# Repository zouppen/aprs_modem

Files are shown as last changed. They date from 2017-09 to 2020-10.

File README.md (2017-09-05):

# aprs_modem
APRS modem using ATmega32u4 and HX1 radio module

## License

This program is free software: you can redistribute it and/or modify
it under the terms of the GNU Affero General Public License as
published by the Free Software Foundation, either version 3 of the
License, or (at your option) any later version.

This program is distributed in the hope that it will be useful, but
WITHOUT ANY WARRANTY; without even the implied warranty of
MERCHANTABILITY or FITNESS FOR A PARTICULAR PURPOSE.  See the GNU
Affero General Public License for more details.

You should have received a copy of the GNU Affero General Public
License along with this program.  If not, see
<http://www.gnu.org/licenses/>.

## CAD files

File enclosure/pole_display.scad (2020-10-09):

use <powerpolish.scad>

// Test print for "standard" pair of plugs
translate([0,0,cupdepth+16.6]) rotate([0,90,0]) poles(2);

// Test print for casing
translate([11,0,cupdepth+wedge_slope*lower_pole_inner_h+thinwall]) rotate([0,90,0]) {
    poles(2,wedge_slope*lower_pole_inner_h+thinwall, framing=true, tongue=false);
}

// Test print for powerpole cap
translate([21,0,cupdepth+cupwidth/2]) rotate([0,90,0]) {
    poles(2,cupwidth/2, tongue=false, cap=true);
}

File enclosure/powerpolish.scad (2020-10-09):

// Anderson PowerPole like housing
// compatible with original contacts.

thinwall=0.8;
cupdepth=8.25;
cupwidth=7.6;
margin=0.2; // make the lower part a bit smaller
backwall=2*thinwall+margin/2;
tongue_angle=18;
tongue_thickness=1;
tongue_rise=7; // Adjust this with the angle
tongue_depth=2.6; // From connector tip to tongue tip
tongue_width=3.5; // On y axis
tonguelike_h = 1.3; // Tongue replacement height
conn_spacing=7.9; // Spacing between connectors
hole_x = 10;
hole_r = 1.1;
wedge_slope = 0.4; // 3D printing aid wedges

// Some magic values
lower_pole_inner_h = cupwidth/2-backwall;

// Square pipe, from origo
module sqpipe(d, w, h, wall) {
    difference() {
        cube([d,w,h]);
        translate([-wall,wall,wall]) {
            cube([d+2*wall,w-2*wall,h-2*wall]);
        }
    }
}

// PowerPolish contact cup, centered on y axis and nudged on z axis
module poletip(d, w, h, wall, wall_bottom, fill=false) {
    difference() {
        // Outer
        translate([0,-w/2,0]) cube([d,w,h]);
        // Inner
        if (!fill)
            translate([-thinwall,-w/2+wall,-wall_bottom]) cube([d,w-2*wall,h]);
    }
}

module pole(backdepth, tongue, cap) {
    // Front part
    difference() {
        union() {
            // Upper part
            poletip(cupdepth+thinwall, cupwidth, cupwidth/2, thinwall, thinwall);
            // Lower part
            rotate([180,0,180]) {
                translate([-(cupdepth+thinwall),0,0]) {
                    lower_pole_h = cupwidth/2-thinwall-margin;
                    poletip(cupdepth+thinwall, cupwidth-2*thinwall-margin, lower_pole_h, thinwall, lower_pole_h - lower_pole_inner_h, cap);
                }
            }
        }
        cube([2*cupdepth,cupwidth+margin,margin], center=true);
    }

    if (cap) {
        // Draw nothing
    } else if (tongue) {
        // Emulates a metal strip
        translate([tongue_rise+tongue_depth,0,-cupwidth/2+thinwall+margin]) {
            tongue(tongue_angle, tongue_width, tongue_rise, tongue_thickness);
        }
    } else {
        // For PCB mounts
        tonguelike_x = cupdepth*0.3; // Visual guess
        translate([tongue_depth,-cupwidth/2+thinwall+margin/2,-lower_pole_inner_h]) {
            cube([tonguelike_x,cupwidth-2*thinwall-margin,tonguelike_h]);
        }
        // PCB mount platform wedge
        translate([tongue_depth+tonguelike_x,cupwidth/2-thinwall-margin/2,-lower_pole_inner_h]) {
            rotate([90,0,0]) wedge(tonguelike_h,wedge_slope,cupwidth-2*thinwall-margin);
        }
    }

    // Cap back is rendered in poles function
    if (!cap) {
        // Back part
        translate([cupdepth,-cupwidth/2,-cupwidth/2]) {
            sqpipe(backdepth, cupwidth, cupwidth, backwall);
        }

        // Back weddge to ease printing
        translate([cupdepth+thinwall,-cupwidth/2,cupwidth/2-backwall]) rotate([90,180,180]) wedge(cupwidth/2-backwall,wedge_slope,cupwidth);
    }
    
    // Front wedge
    lower_height=cupwidth/2-thinwall-1.5*margin;
    translate([thinwall,cupwidth/2-thinwall-margin/2,-lower_height-margin/2]) rotate([90,0,0]) wedge(lower_height,wedge_slope,cupwidth-2*thinwall-margin);
    
}

module tongue(angle, width, length, thickness) {
    intersection () {
        difference() {
            rotate([0,angle,0]) {
                cube([3*length,width,thickness], center=true);
            }
            translate([0,0,-length]) {
                cube([3*length,width*2,2*length], center=true);
            }
        }
        cube([2*length, 2*width, length*2], center=true); 
    }
}

module poles(count, backdepth=16.6, framing=false, tongue=true, cap=false) {
    ends = framing ? [0 : 1: count] : [1 : 1: count-1];

    difference() {
        union() {
            // Actual poles
            for (i = [0 : 1: count-1]) {
                translate([0,conn_spacing*i,0]) {
                    pole(backdepth, tongue, cap);
                }
            }

            // Fill gaps between the poles
            for (i = ends) {
                translate([0,conn_spacing*i,0]) {
                    gapwidth=conn_spacing-cupwidth;
                    translate([0,(-conn_spacing-gapwidth)/2,margin/2]) {
                        cube([backdepth+cupdepth,gapwidth,cupwidth/2-margin/2]);
                    }
                    translate([cupdepth, cupwidth/2-conn_spacing, -cupwidth/2]) {
                        cube([backdepth, gapwidth, cupwidth]);
                    }
                }
            }

            if (cap) {
                translate([cupdepth, -cupwidth/2, -cupwidth/2]) {
                    cube([backdepth, (count-1)*conn_spacing+cupwidth, cupwidth]);
                }
            }
            
            // Add bottom support if framing used
            if (framing) {
                // Inner gap
                translate([cupdepth,cupwidth/2-conn_spacing,-cupwidth/2]) {
                    mirror([0,0,1]) {
                        cube([backdepth,(count+1)*conn_spacing-cupwidth,conn_spacing-cupwidth]);
                    }
                }
                // Lowest support
                translate([0,cupwidth/2-conn_spacing,-conn_spacing/2]) {
                    mirror([0,0,1]) {
                        cube([cupdepth+backdepth,(count+1)*conn_spacing-cupwidth,thinwall]);
                    }
                }
                
                // Side covers
                for (y_pos = [0, count*conn_spacing+thinwall]) {
                    translate([0,-thinwall-conn_spacing/2+y_pos,-conn_spacing/2-thinwall]) {
                        cube([cupdepth+backdepth,thinwall,cupwidth/2+conn_spacing/2+thinwall]);
                    }
                }
            }
        }
        
        // Add holes
        if (!framing && !cap) {
            for (i = [1 : 1 : count-1]) {
                translate([hole_x,i*conn_spacing-cupwidth/2,-cupwidth]) {
                    cylinder(cupwidth*2, hole_r, hole_r, $fn=16);
                }
            }
        }
    }
}

module wedge(x, slope, z) {
    linear_extrude(z)
        polygon([[0,0], [0,x], [slope*x,0]]);
}

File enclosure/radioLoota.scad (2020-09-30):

//pls don't judge too much
//my first .scad file

hyla=6;
hala=7;
h=hyla + hala + 2;
w=28;
l=60;
wall=3;

sisa =  [w,l,h];
ulko = [for (i = sisa) i+6];
usb = [9,4,wall];

module cube1(){
    difference() {
        translate ([0,0,-wall])cube(ulko);
        translate([wall,wall,0]) cube(sisa);
        }
}

module cube2(){
difference(){
    cube1();
    translate([8+wall,0,0]) cube(usb);
    }

}
module cube3(){
difference(){
    cube2();
    translate([0,(l+wall),0]) 
cube([100,100,h]);
    }
}

module cube4(){
difference(){
    cube3();
    rotate([0,90,0])
    translate([0,(l+wall),wall]) 
    cylinder(r=1,h=w);
    }
}

module cube5(){
difference(){
    cube4();
    rotate([0,90,0])
    translate([-h,(l+wall),wall]) 
    cylinder(r=1,h=w);
    }
}

cube5();
translate([2,0,hala - wall]) cube([wall,l,wall]);
translate([2,0,h-hyla]) cube([wall,l,wall]);

translate([w+1,0,hala - wall]) cube([wall,l,wall]);
translate([w+1,0,h-hyla]) cube([wall,l,wall]);

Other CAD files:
enclosure/radioLootaLid.scad

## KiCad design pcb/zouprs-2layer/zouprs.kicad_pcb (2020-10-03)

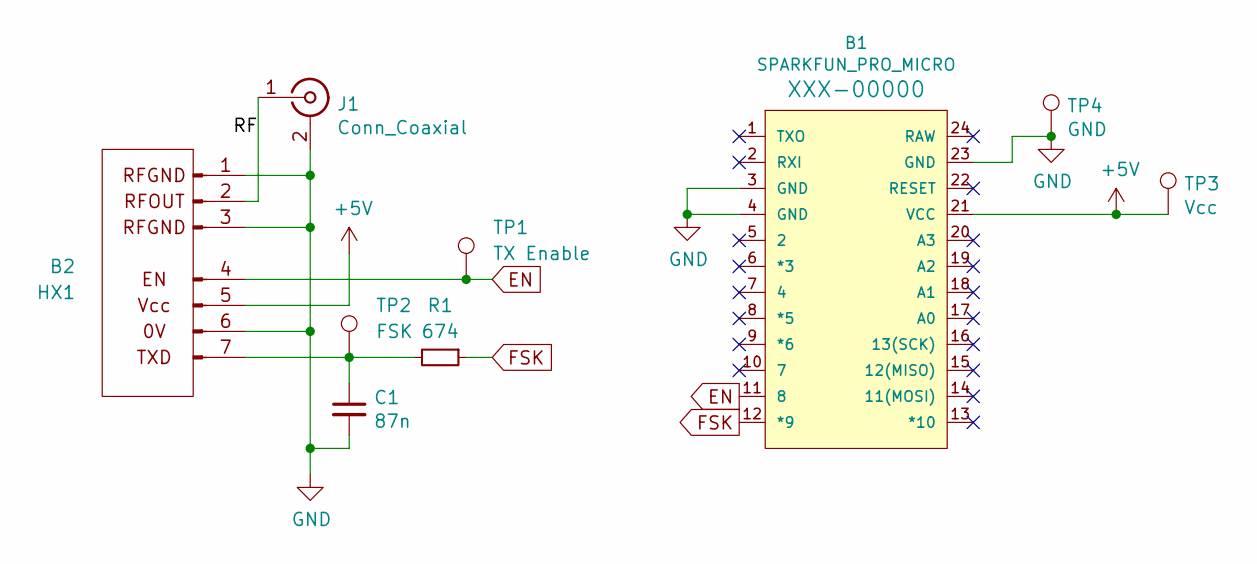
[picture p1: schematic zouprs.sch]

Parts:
B1: SPARKFUN_PRO_MICRO
B2: HX1; PinHeader_1x12_P2.54mm_Vertical
C1: 87n; C_1206_3216Metric_Pad1.42x1.75mm_HandSolder
J1: Conn_Coaxial; SMA_Samtec_SMA-J-P-X-ST-EM1_EdgeMount
R1: 674; R_1206_3216Metric_Pad1.42x1.75mm_HandSolder
TP1: TX Enable; TestPoint_Pad_D1.0mm
TP2: FSK; TestPoint_Pad_D1.0mm
TP3: Vcc; TestPoint_Pad_D1.0mm
TP4: GND; TestPoint_Pad_D1.0mm

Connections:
+5V: B1.21 (VCC), B2.5 (GND), TP3.1
EN: B1.11 (8), B2.4 (EN), TP1.1
FSK: B1.12 (*9), R1.1
GND: B1.3 (GND), B1.4 (GND), B1.23 (GND), B2.1 (RFGND), B2.3 (RFGND), B2.6 (VCC), C1.2, J1.2 (Ext), TP4.1
unnamed: B2.2 (RFOUT), J1.1 (In)
unnamed: B2.7 (TXD), C1.1, R1.2, TP2.1

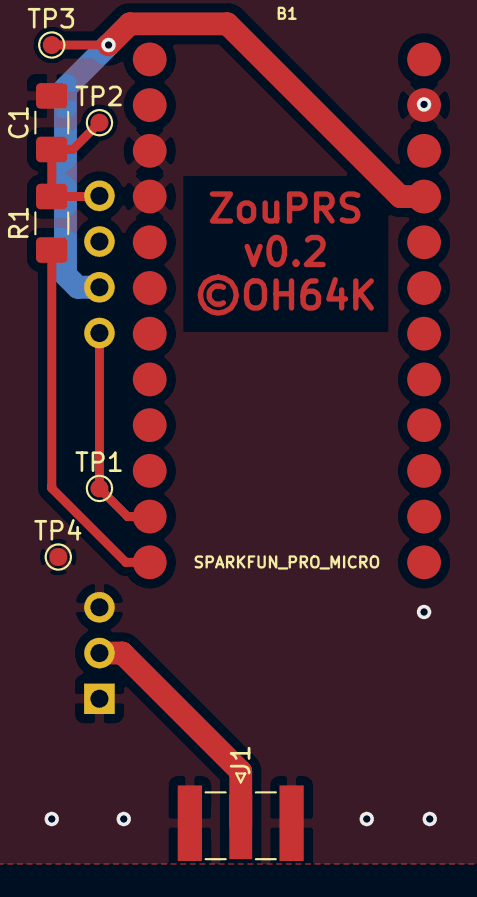
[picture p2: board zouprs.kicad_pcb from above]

Board: 2 copper layers, 9 parts (1 on the bottom side), 6 nets.

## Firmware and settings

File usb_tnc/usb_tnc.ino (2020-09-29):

// Include LibAPRS
#include <LibAPRS.h>
#include <TimerOne.h>

#define KISS_STATE_DATA 0
#define KISS_STATE_CMD 1
#define KISS_STATE_ESC 2
#define KISS_STATE_END 3

#define FEND 0xC0
#define FESC 0xDB
#define TFEND 0xDC
#define TFESC 0xDD

#define TXD_PIN 9
#define EN_PIN 8

extern Afsk *AFSK_modem;
extern AX25Ctx AX25;
uint8_t AFSK_dac_isr(Afsk *afsk);

void setup() {
    // Set up serial port
    Serial.begin(9600);
    pinMode(TXD_PIN, OUTPUT);
    
    Timer1.initialize(64); // set a timer of length 100000 microseconds (or 0.1 sec - or 10Hz => the led will blink 5 times, 5 cycles of on-and-off, per second)
    Timer1.pwm(TXD_PIN, 512);
    Timer1.attachInterrupt( timerIsr ); // attach the service routine here

    // Initialise APRS library - This starts the modem
    APRS_init(EN_PIN);
    DDRB &= ~(1<<0); // Start with RX LED off (or set to INPUT mode)
  
    // You must at a minimum configure your callsign and SSID
    APRS_setCallsign("OH6EYA", 1);
    APRS_setPreamble(250);
}

void loop() {
    static uint8_t msg[256];
    static uint8_t msg_i = 0;
    static uint8_t state = KISS_STATE_END;
  
    while (Serial.available()) {
	DDRB |= (1<<0); // Any serial traffic turns on RX LED
	uint8_t c = Serial.read();

	// Send if FEND and we have something to send
	if (c == FEND) {
	    if (state == KISS_STATE_DATA && msg_i != 0) {
		DDRB &= ~(1<<0); // Datagram completed, turn off RX LED
		ax25_sendRaw(&AX25, msg, msg_i);
		msg_i = 0;
	    }
	    state = KISS_STATE_CMD;
	    continue;
	}

	if (state == KISS_STATE_CMD) {
	    // We currently support only frame at first TNC
	    state = c == 0x00 ? KISS_STATE_DATA : KISS_STATE_END;
	    continue;
	}

	// Must set before decoding escapes
	if (state == KISS_STATE_DATA && c == FESC) {
	    state = KISS_STATE_ESC;
	    continue;
	}
	
	// Decode escape
	if (state == KISS_STATE_ESC) {
	    switch (c) {
	    case TFEND:
		c = FEND;
		break;
	    case TFESC:
		c = FESC;
		break;
	    default:
		// Garbage
		state = KISS_STATE_END;
		continue;
	    }
	    state = KISS_STATE_DATA;
	}

	if (state == KISS_STATE_DATA) {
	    if (msg_i >= sizeof(msg)) {
		// Too long content
		state = KISS_STATE_END;
	    } else {
		msg[msg_i++] = c;
	    }
	}
	// Else: error state; do nothing	
    }
}

void timerIsr()
{
    // Set new value for PWM
    Timer1.pwm(TXD_PIN, (int)AFSK_dac_isr(AFSK_modem) << 2);
}

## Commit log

2020-09-29 Make it support new ZouPRS board
2020-09-30 Enclosure added
    [radioLoota.scad, radioLootaLid.scad]
2020-09-30 minor tweaks
    [radioLoota.scad, radioLootaLid.scad]
2020-10-01 Add PCB
    [zouprs.kicad_pcb, zouprs.sch]
2020-10-03 Make dual side PCB
    [zouprs.kicad_pcb, zouprs.sch]
2020-10-03 Move Arduino board about 1mm up
    [zouprs.kicad_pcb]
2020-10-03 Add some ground vias to RF end of the board
    [zouprs.kicad_pcb]
2020-10-03 Small tweaks to test point
    [zouprs.kicad_pcb]
2020-10-06 Add simple "powerpolish" plug
    [powerpolish.scad]
2020-10-06 Outer dimensions match
    [powerpolish.scad]
2020-10-06 Add double powerpolish
    [powerpolish.scad]
2020-10-06 Add tongue
    [powerpolish.scad]
2020-10-06 Add some comments to the variables
    [powerpolish.scad]
2020-10-07 Add support for parametric pole arrays
    [powerpolish.scad]
2020-10-07 Add wedges for easier printing
    [powerpolish.scad]
2020-10-07 Tongue at too back, blocking the connector. Fixing.
    [powerpolish.scad]
2020-10-07 Add support for framing
    [powerpolish.scad]
2020-10-07 Add framing support for poles (case mount)
    [powerpolish.scad]
2020-10-08 Fix back wedge so that it's not inside back wall
    [powerpolish.scad]
2020-10-08 Fine-tune lower cup lower wall thickness. Calculate it form back wall thickness
    [powerpolish.scad]
2020-10-08 Make different kind of tongue to PCB mount block
    [powerpolish.scad]
2020-10-08 Fix slope math in wedges
    [powerpolish.scad]
2020-10-08 Add support for protective cap for Anderson Powerpole
    [powerpolish.scad]
2020-10-09 enclosure: Make cup of the cap filled to top
    [powerpolish.scad]
2020-10-09 enclosure: Tongue must be thicker to not to break
    [powerpolish.scad]
2020-10-09 enclosure: Connector support should be higher and the round hole larger
    [powerpolish.scad]
2020-10-09 enclosure: Move parametric model to a separate file
    [pole_display.scad, powerpolish.scad]

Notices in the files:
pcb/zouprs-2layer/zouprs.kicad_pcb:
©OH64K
